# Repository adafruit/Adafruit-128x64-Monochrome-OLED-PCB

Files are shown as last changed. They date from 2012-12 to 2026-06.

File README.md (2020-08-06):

## Adafruit 128x64 Monochrome OLED PCB
<a href="http://www.adafruit.com/products/326"><br/>
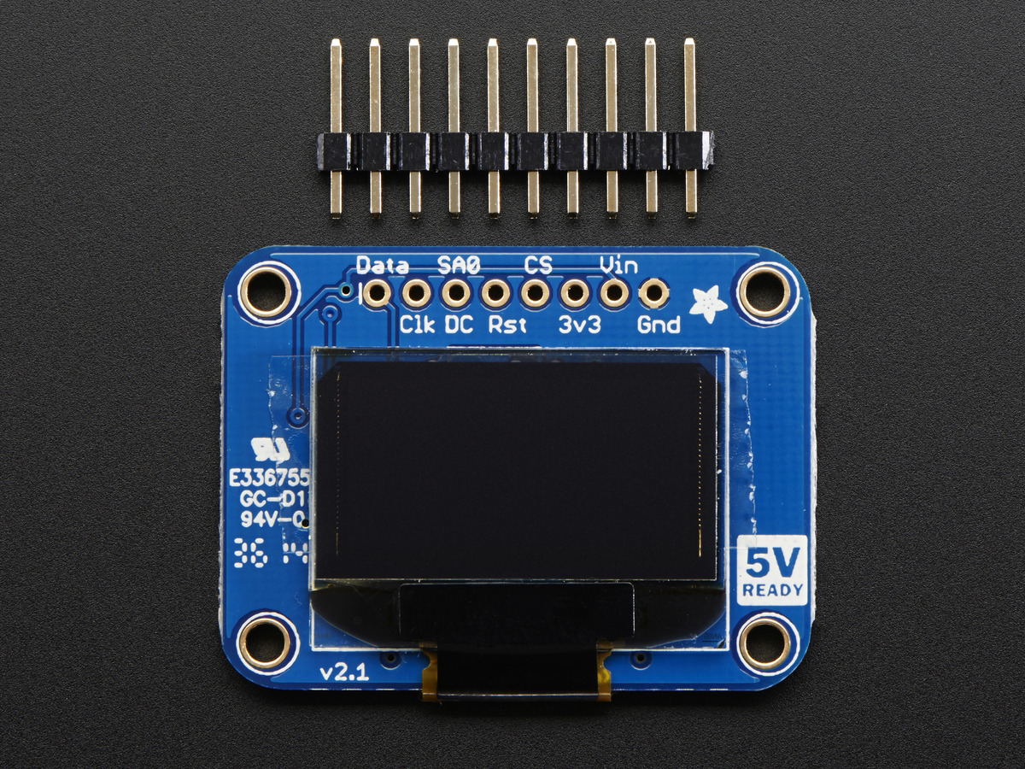
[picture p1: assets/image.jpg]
<a href="http://www.adafruit.com/products/326"><br/>
Click here to purchase one from the Adafruit shop</a>

These displays are small, only about 1" diagonal, but very readable due to the high contrast of an OLED display. This display is made of 128x64 individual white OLED pixels, each one is turned on or off by the controller chip. Because the display makes its own light, no backlight is required. This reduces the power required to run the OLED and is why the display has such high contrast; we really like this miniature display for its crispness!

This breakout can be used with either an SPI or I2C interface - selectable by soldering two jumpers on the back. The design is completely 5V-ready, with an onboard regulator and built in boost converter. It's easier than ever to connect directly to your 3V or 5V microcontroller without needing any kind of level shifter!

This is the PCB for the Adafruit 128x64 I2C/SPI/Parallel OLED breakout board. The format is EagleCAD schematic and board layout
- http://www.adafruit.com/products/326

### License

Adafruit invests time and resources providing this open source design, please support Adafruit and open-source hardware by purchasing products from [Adafruit](https://www.adafruit.com)!

All text above must be included in any redistribution

Designed by Limor Fried/Ladyada for Adafruit Industries.
Creative Commons Attribution/Share-Alike, all text above must be included in any redistribution. 
See license.txt for additional information.

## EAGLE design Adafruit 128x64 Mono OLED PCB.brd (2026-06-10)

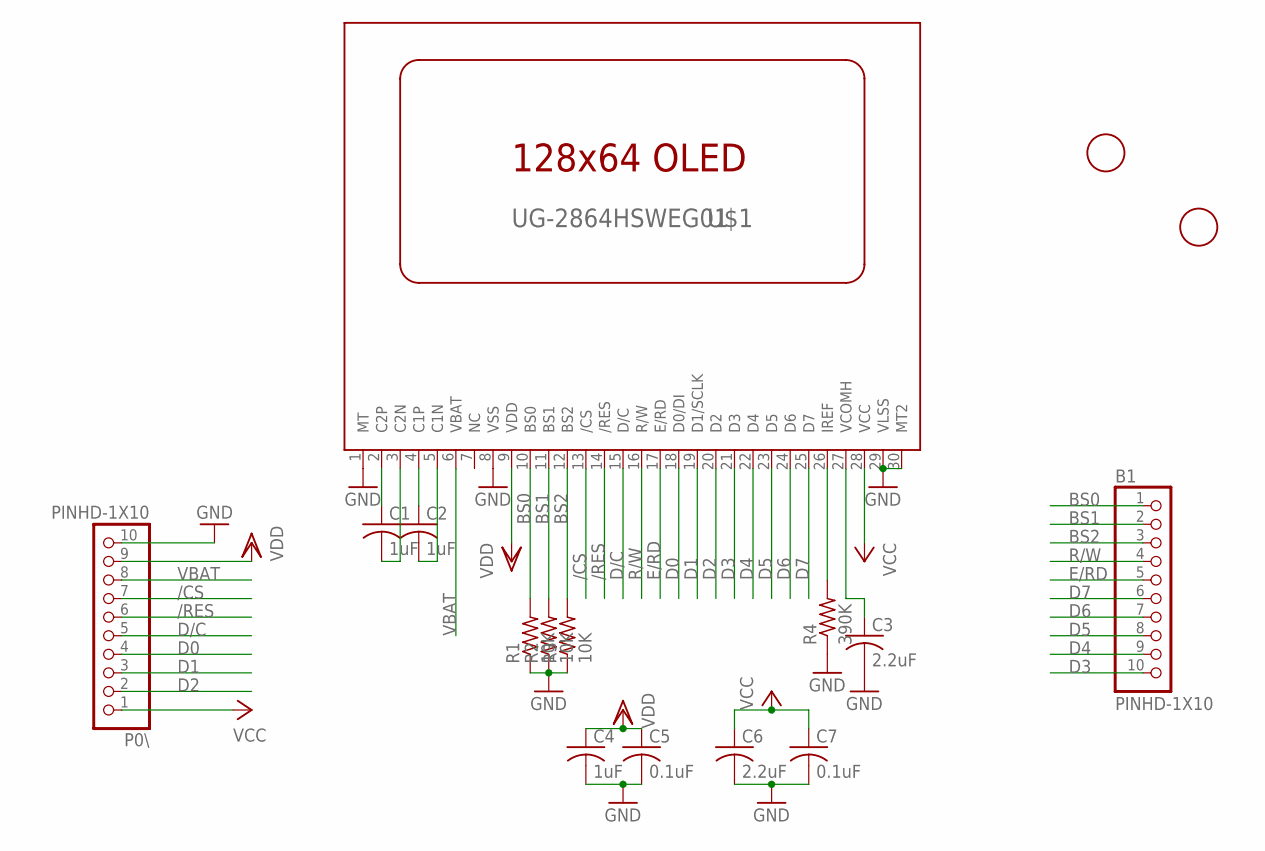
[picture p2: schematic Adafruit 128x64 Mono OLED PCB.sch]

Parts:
B1: PINHD-1X10; 1X10-BIG
C1, C2, C4: 1uF; C0805K
C3, C6: 2.2uF; C0805K
C5, C7: 0.1uF; C0805K
P0\: PINHD-1X10; 1X10-BIG
R1, R2, R3: 10K; R0805
R4: 390K; R0805
U$1: UG-2864HSWEG01; 1X30-0.7MM
U$3, U$4: FIDUCIAL; FIDUCIAL_1MM

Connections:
/CS: P0\.7, U$1.13 (/CS)
/RES: P0\.6, U$1.14 (/RES)
BS0: B1.1, R1.2, U$1.10 (BS0)
BS1: B1.2, R2.2, U$1.11 (BS1)
BS2: B1.3, R3.2, U$1.12 (BS2)
D0: P0\.4, U$1.18 (D0/DI)
D1: P0\.3, U$1.19 (D1/SCLK)
D2: P0\.2, U$1.20 (D2)
D3: B1.10, U$1.21 (D3)
D4: B1.9, U$1.22 (D4)
D5: B1.8, U$1.23 (D5)
D6: B1.7, U$1.24 (D6)
D7: B1.6, U$1.25 (D7)
D/C: P0\.5, U$1.15 (D/C)
E/RD: B1.5, U$1.17 (E/RD)
GND: C3.2, C4.2, C5.2, C6.2, C7.2, P0\.10, R1.1, R2.1, R3.1, R4.1, U$1.1 (MT), U$1.8 (VSS), U$1.29 (VLSS), U$1.30 (MT2)
unnamed: C1.2, U$1.3 (C2N)
unnamed: C1.1, U$1.2 (C2P)
unnamed: C2.1, U$1.4 (C1P)
unnamed: C2.2, U$1.5 (C1N)
unnamed: R4.2, U$1.26 (IREF)
unnamed: C3.1, U$1.27 (VCOMH)
R/W: B1.4, U$1.16 (R/W)
VBAT: P0\.8, U$1.6 (VBAT)
VCC: C6.1, C7.1, P0\.1, U$1.28 (VCC)
VDD: C4.1, C5.1, P0\.9, U$1.9 (VDD)

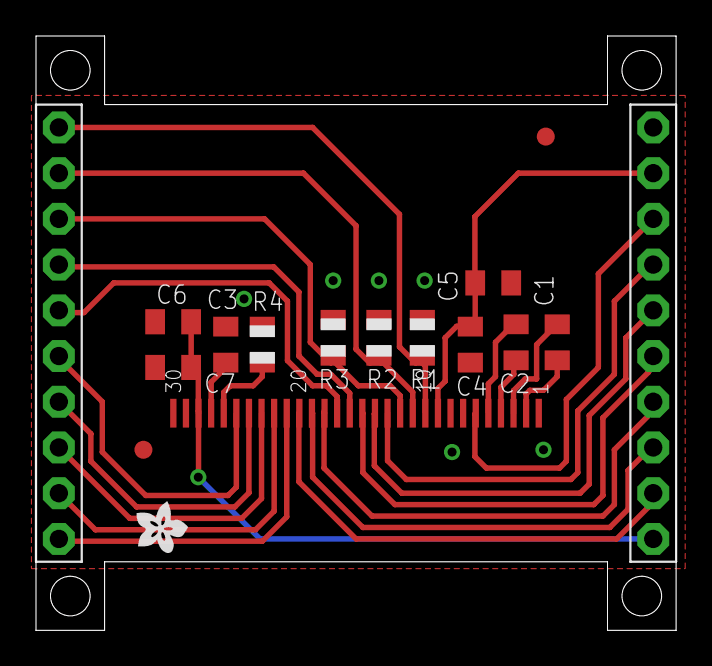
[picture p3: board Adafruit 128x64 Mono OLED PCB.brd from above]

Board: 2 copper layers, 35.6 x 33.0 mm, 17 parts (0 on the bottom side), 26 nets.

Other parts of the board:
U$2: ADAFRUIT200MIL

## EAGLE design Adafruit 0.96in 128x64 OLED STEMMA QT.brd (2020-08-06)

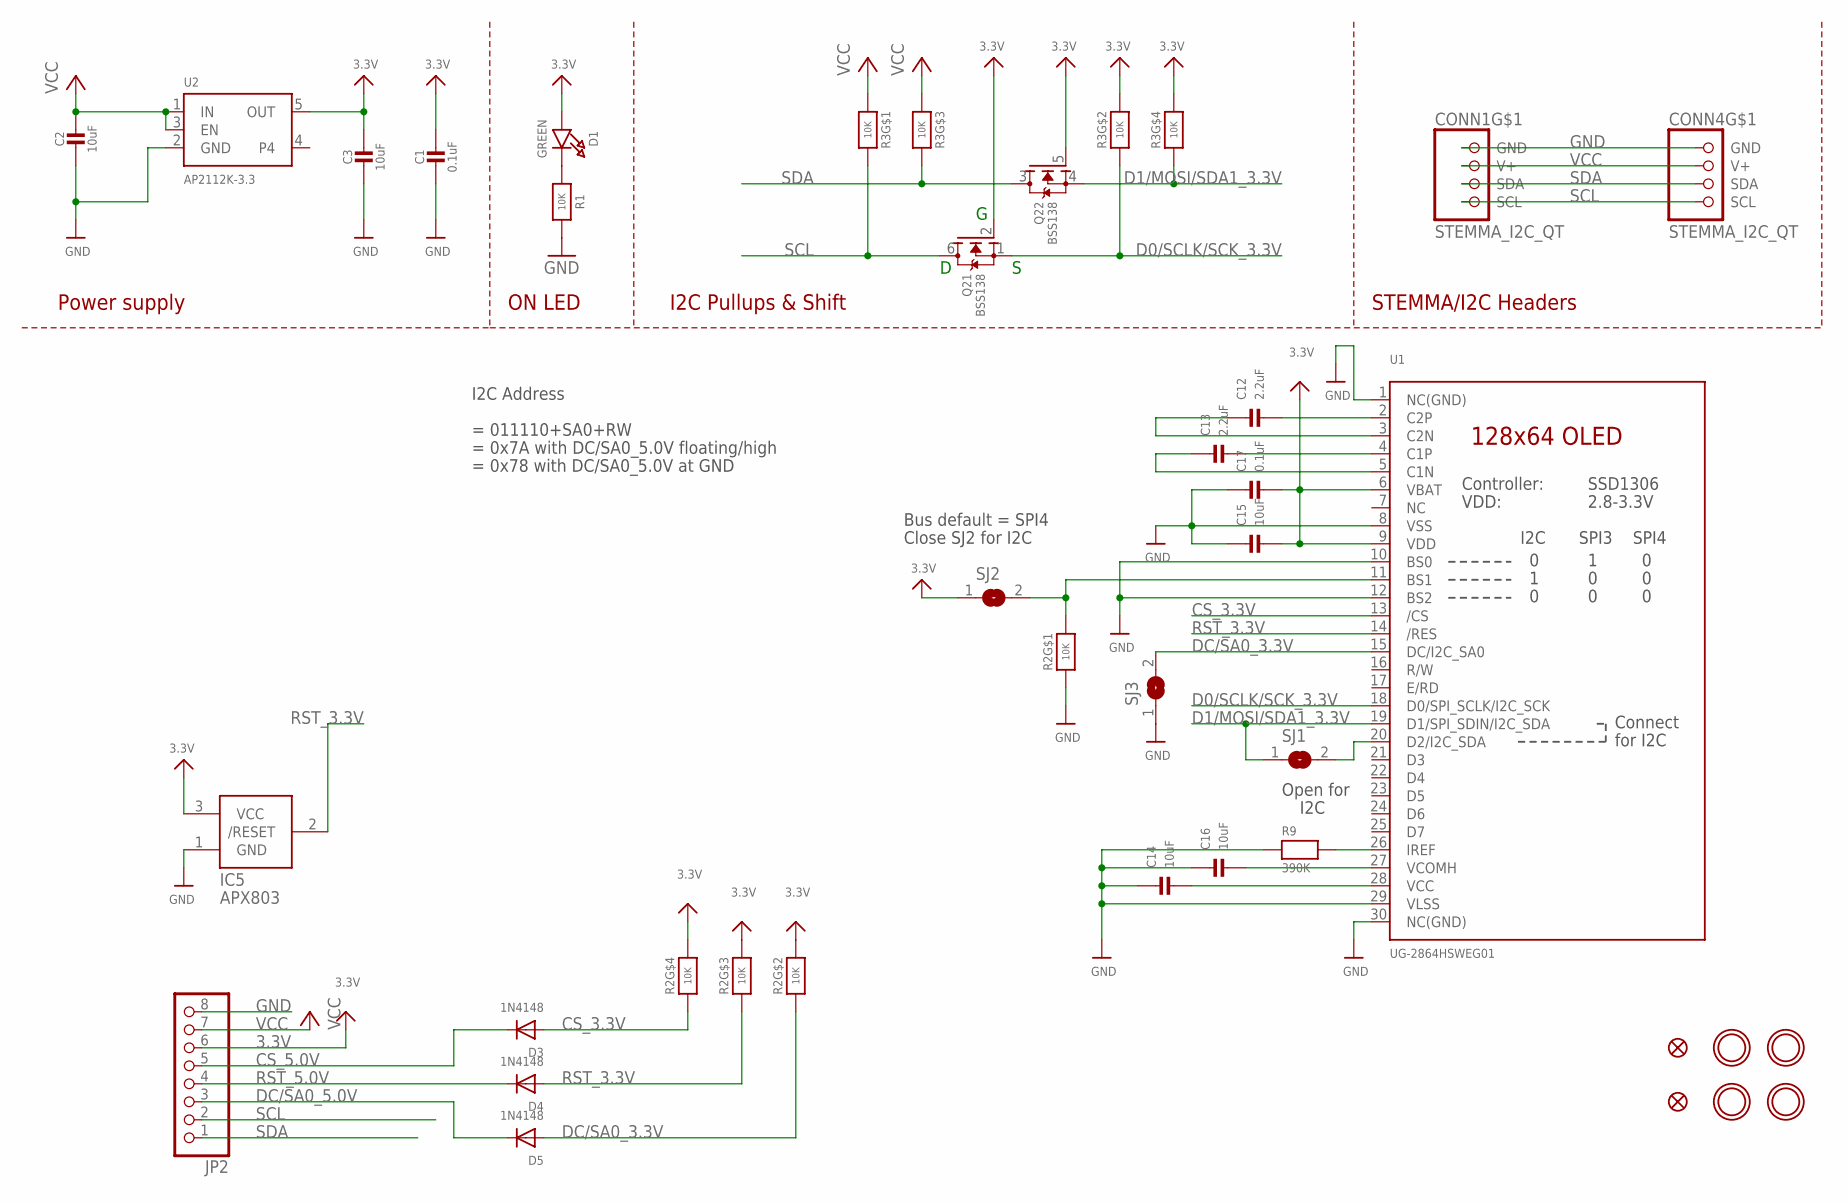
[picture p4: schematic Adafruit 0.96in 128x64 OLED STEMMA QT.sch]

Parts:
C1, C17: 0.1uF; 0603-NO
C2, C3, C14, C15, C16: 10uF; 0805-NO
C12, C13: 2.2uF; 0805-NO
CONN1, CONN4: STEMMA_I2C_QT; JST_SH4
D1: GREEN; CHIPLED_0603_NOOUTLINE
D3, D4, D5: 1N4148; SOD-323
FID3, FID4: FIDUCIAL_1MM
IC5: APX803; SOT23
JP2: HEADER-1X870MIL; 1X08_ROUND_70
Q2: BSS138; SOT363
R1: 10K; 0603-NO
R2, R3: 10K; RESPACK_4X0603
R9: 390K; 0603-NO
SJ1, SJ2: SOLDERJUMPERCLOSED; SOLDERJUMPER_CLOSEDWIRE
SJ3: SOLDERJUMPER; SOLDERJUMPER_ARROW_NOPASTE
U1: UG-2864HSWEG01; UG-2864HSWEG01_0.96IN_WRAPAROUND
U2: AP2112K-3.3; SOT23-5
U$1, U$17, U$19, U$21: MOUNTINGHOLE2.5; MOUNTINGHOLE_2.5_PLATED

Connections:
3.3V: C1.1, C3.1, C15.2, C17.2, D1.A, IC5.3 (VCC), JP2.6, Q2.2 (G), Q2.5 (G), R2.5 (2), R2.6 (2), R2.7 (2), R3.2 (1), R3.4 (1), SJ2.1, U1.6 (VBAT), U1.9 (VDD), U2.5 (OUT)
CS_3.3V: D3.A, R2.4 (1), U1.13 (/CS)
CS_5.0V: D3.C, JP2.5
D0/SCLK/SCK_3.3V: Q2.1 (S), R3.7 (2), U1.18 (D0/SPI_SCLK/I2C_SCK)
D1/MOSI/SDA1_3.3V: Q2.4 (S), R3.5 (2), SJ1.1, U1.19 (D1/SPI_SDIN/I2C_SDA)
DC/SA0_3.3V: D5.A, R2.2 (1), SJ3.2, U1.15 (DC/I2C_SA0)
DC/SA0_5.0V: D5.C, JP2.3
GND: C1.2, C2.2, C3.2, C14.1, C15.1, C16.1, C17.1, CONN1.1 (GND), CONN4.1 (GND), IC5.1 (GND), JP2.8, R1.2, R2.1, R9.1, SJ3.1, U1.1 (NC(GND)), U1.8 (VSS), U1.10 (BS0), U1.12 (BS2), U1.29 (VLSS), U1.30 (NC(GND)), U2.2 (GND)
unnamed: D1.C, R1.1
unnamed: R2.8 (2), SJ2.2, U1.11 (BS1)
unnamed: R9.2, U1.26 (IREF)
unnamed: C12.2, U1.2 (C2P)
unnamed: C12.1, U1.3 (C2N)
unnamed: C13.2, U1.4 (C1P)
unnamed: C13.1, U1.5 (C1N)
unnamed: C14.2, U1.28 (VCC)
unnamed: C16.2, U1.27 (VCOMH)
unnamed: SJ1.2, U1.20 (D2/I2C_SDA)
RST_3.3V: D4.A, IC5.2 (/RESET), R2.3 (1), U1.14 (/RES)
RST_5.0V: D4.C, JP2.4
SCL: CONN1.4 (SCL), CONN4.4 (SCL), JP2.2, Q2.6 (D), R3.8 (2)
SDA: CONN1.3 (SDA), CONN4.3 (SDA), JP2.1, Q2.3 (D), R3.6 (2)
VCC: C2.1, CONN1.2 (V+), CONN4.2 (V+), JP2.7, R3.1, R3.3 (1), U2.1 (IN), U2.3 (EN)

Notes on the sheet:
I2C Pullups & Shift
STEMMA/I2C Headers
ON LED
Power supply
Bus default = SPI4
Close SJ2 for I2C
= 011110+SA0+RW
= 0x7A with DC/SA0_5.0V floating/high
= 0x78 with DC/SA0_5.0V at GND
I2C Address
Open for
I2C

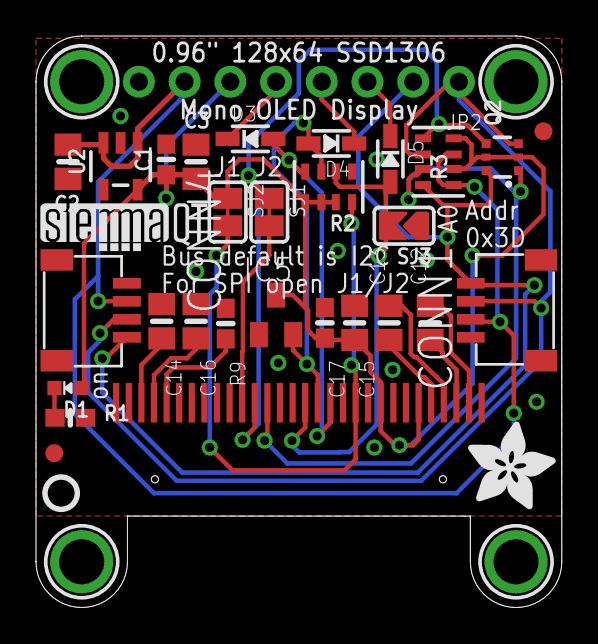
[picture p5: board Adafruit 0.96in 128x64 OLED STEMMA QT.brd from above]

Board: 2 copper layers, 29.2 x 31.8 mm, 36 parts (1 on the bottom side), 23 nets.

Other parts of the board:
U$8: ADAFRUIT_5MM
U$25: PCBFEAT-REV-040
U$31: STEMMAQT

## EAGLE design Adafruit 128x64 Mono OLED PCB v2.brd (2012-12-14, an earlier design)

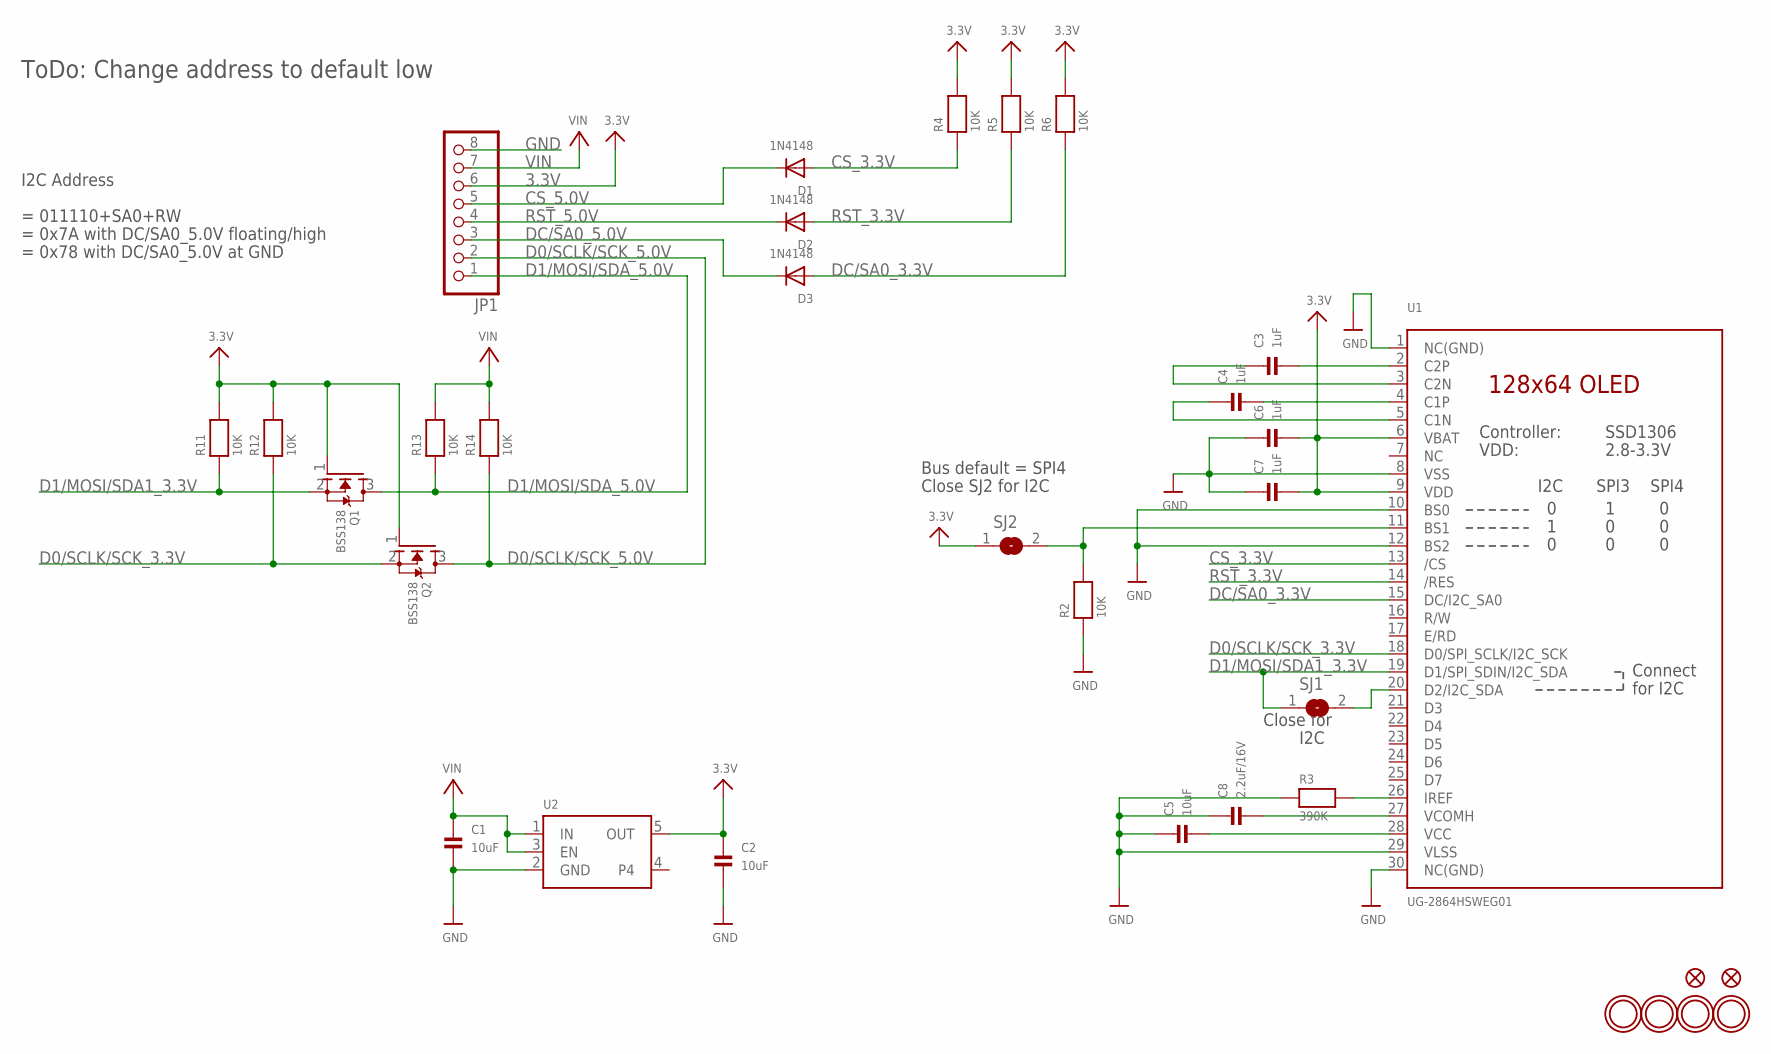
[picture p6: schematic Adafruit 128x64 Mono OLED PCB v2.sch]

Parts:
C1, C2, C5: 10uF; 0805
C3, C4, C6, C7: 1uF; 0805
C8: 2.2uF/16V; 0805
D1, D2, D3: 1N4148; SOD-323
FID1, FID2: FIDUCIAL""; FIDUCIAL_1MM
JP1: HEADER-1X870MIL; 1X08_ROUND_70
Q1, Q2: BSS138; SOT23-WIDE
R2, R4, R5, R6, R11, R12, R13, R14: 10K; 0805
R3: 390K; 0805
SJ1, SJ2: SOLDERJUMPERREFLOW_NOPASTE; SOLDERJUMPER_REFLOW_NOPASTE
U1: UG-2864HSWEG01; UG-2864HSWEG01_0.96IN_WRAPAROUND
U2: VREG_SOT23-5; SOT23-5
U$23, U$24, U$25, U$26: MOUNTINGHOLE2.5; MOUNTINGHOLE_2.5_PLATED

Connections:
3.3V: C2.1, C6.2, C7.2, JP1.6, Q1.1 (G), Q2.1 (G), R4.2, R5.2, R6.2, R11.2, R12.2, SJ2.1, U1.6 (VBAT), U1.9 (VDD), U2.5 (OUT)
CS_3.3V: D1.A, R4.1, U1.13 (/CS)
CS_5.0V: D1.C, JP1.5
D0/SCLK/SCK_3.3V: Q2.2 (S), R12.1, U1.18 (D0/SPI_SCLK/I2C_SCK)
D0/SCLK/SCK_5.0V: JP1.2, Q2.3 (D), R14.1
D1/MOSI/SDA1_3.3V: Q1.2 (S), R11.1, SJ1.1, U1.19 (D1/SPI_SDIN/I2C_SDA)
D1/MOSI/SDA_5.0V: JP1.1, Q1.3 (D), R13.1
DC/SA0_3.3V: D3.A, R6.1, U1.15 (DC/I2C_SA0)
DC/SA0_5.0V: D3.C, JP1.3
GND: C1.2, C2.2, C5.1, C6.1, C7.1, C8.1, JP1.8, R2.1, R3.1, U1.1 (NC(GND)), U1.8 (VSS), U1.10 (BS0), U1.12 (BS2), U1.29 (VLSS), U1.30 (NC(GND)), U2.2 (GND)
unnamed: R2.2, SJ2.2, U1.11 (BS1)
unnamed: SJ1.2, U1.20 (D2/I2C_SDA)
unnamed: R3.2, U1.26 (IREF)
unnamed: C3.2, U1.2 (C2P)
unnamed: C3.1, U1.3 (C2N)
unnamed: C4.2, U1.4 (C1P)
unnamed: C4.1, U1.5 (C1N)
unnamed: C5.2, U1.28 (VCC)
unnamed: C8.2, U1.27 (VCOMH)
RST_3.3V: D2.A, R5.1, U1.14 (/RES)
RST_5.0V: D2.C, JP1.4
VIN: C1.1, JP1.7, R13.2, R14.2, U2.1 (IN), U2.3 (EN)

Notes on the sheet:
Bus default = SPI4
Close SJ2 for I2C
= 011110+SA0+RW
= 0x7A with DC/SA0_5.0V floating/high
= 0x78 with DC/SA0_5.0V at GND
I2C Address
ToDo: Change address to default low
Close for
I2C

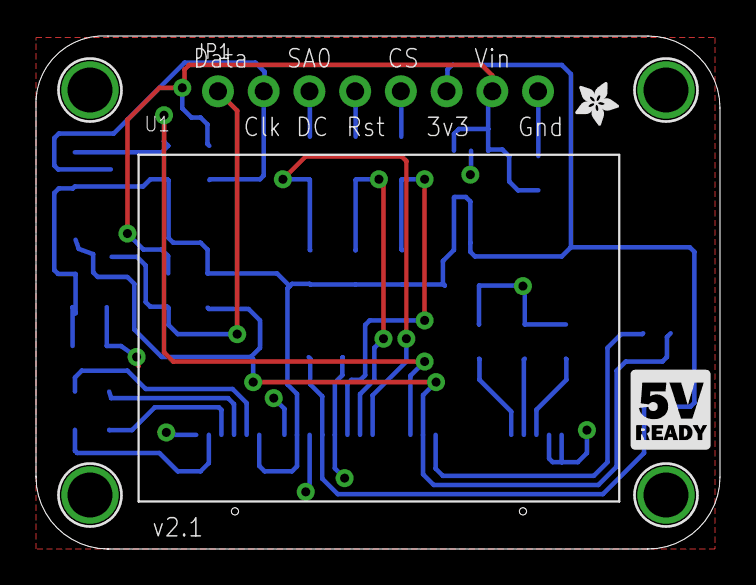
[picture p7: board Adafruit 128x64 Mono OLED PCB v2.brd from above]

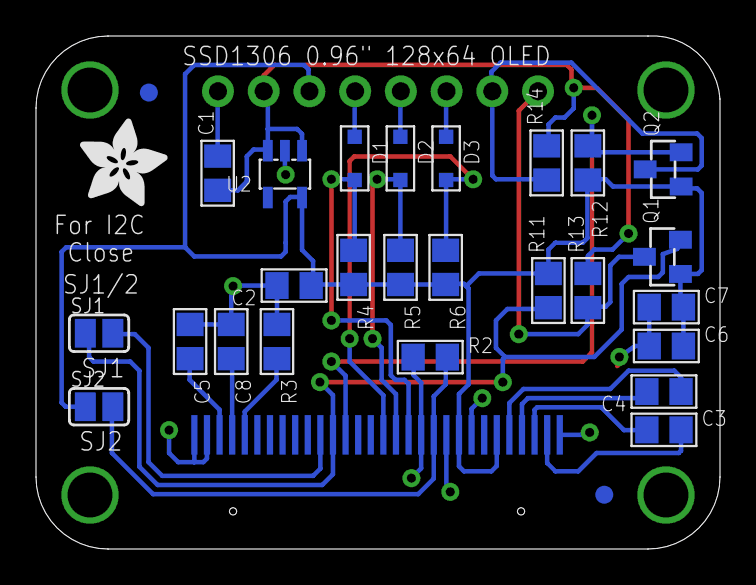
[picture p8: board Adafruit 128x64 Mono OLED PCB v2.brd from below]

Board: 2 copper layers, 38.0 x 28.5 mm, 36 parts (28 on the bottom side), 22 nets.

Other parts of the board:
U$3: ADAFRUIT_5MM
U$27: ADAFRUIT_2.5MM
U$28: LOGIC_5VREADY_5MM

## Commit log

2011-08-12 Board & schem files for 128x64 oled
    [SSD1306.brd, SSD1306.sch]
2020-08-06 Adding updated board files.
    [Adafruit 0.96in 128x64 OLED STEMMA QT.brd, Adafruit 0.96in 128x64 OLED STEMMA QT.sch]
2026-06-03 update file format to XML
    [Adafruit 128x64 Mono OLED PCB.brd, Adafruit 128x64 Mono OLED PCB.sch]

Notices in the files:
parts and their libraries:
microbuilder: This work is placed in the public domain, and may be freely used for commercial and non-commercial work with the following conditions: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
